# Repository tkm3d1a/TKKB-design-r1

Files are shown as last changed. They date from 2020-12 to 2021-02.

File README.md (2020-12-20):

# TKKB-design-r1
 TKm3d1a Keyboard design project, revision 1

MY first attempt at using Github for rev control and publishing of any/all files in KB design.

The Goal is a 60% ish keyboard design, no multiple layout support.  Exposed diodes, with a swapable MCU.

Possibly also add numpad support as I personally use the numpad often.  

Designed to use PCB mount MX style switches.

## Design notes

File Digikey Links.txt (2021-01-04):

MCU - ATMega32A
https://www.digikey.com/en/products/detail/microchip-technology/ATMEGA32A-PU/1914592

Crystal - HC49 Pkg - LFXTAL003231BULK
https://www.digikey.com/en/products/detail/iqd-frequency-products/LFXTAL003231BULK/8633676

22uF Cap - Radial, Can D5x2 Pkg - ECE-A1AN220U
https://www.digikey.com/en/products/detail/panasonic-electronic-components/ECE-A1AN220U/227593

4u7F Cap - Radial, Can D5x2 Pkg - UKL1E4R7KDDANA
https://www.digikey.com/en/products/detail/nichicon/UKL1E4R7KDDANA/2598437

0u1F Cap - Disc, 5.1Lx3.2W with 5.1 Pitch - SR215C104JARTR1
https://www.digikey.com/en/products/detail/avx-corporation/SR215C104JARTR1/9948450

5k1 RES - Axial, Horiz, 3.6x1.6 - MBA02040C5101FCT00
https://www.digikey.com/en/products/detail/vishay-beyschlag-draloric-bc-components/MBA02040C5101FCT00/6138797

10k RES - Axial, Horiz, 3.6x1.6 - MRS16000C1002FRP00
https://www.digikey.com/en/products/detail/vishay-beyschlag-draloric-bc-components/MRS16000C1002FRP00/5063735

75R RES - Axial, Horiz, 3.6x1.6 - MBA02040C7509FC100
https://www.digikey.com/en/products/detail/vishay-beyschlag-draloric-bc-components/MBA02040C7509FC100/7350982

3.6v Z-Diode - Axial, DO-35 PKG - BZX79-C3V6,133
https://www.digikey.com/en/products/detail/nexperia-usa-inc/BZX79-C3V6133/2762641

Gen Purp 75V/300mA Diode - Axial, DO-35 PKG - 1N4148TR
https://www.digikey.com/en/products/detail/vishay-semiconductor-diodes-division/1N4148TR/3104054

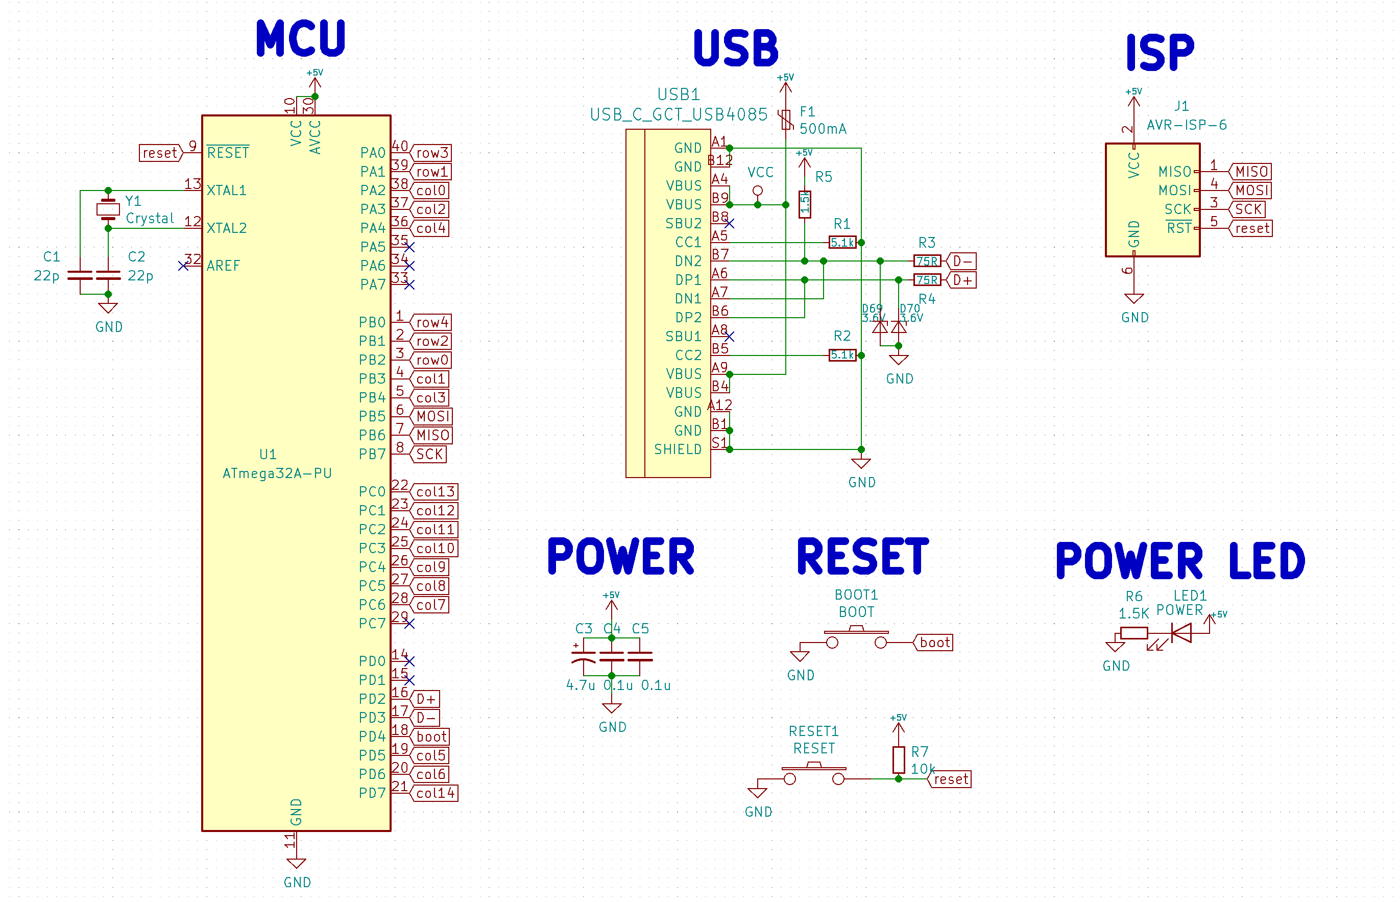
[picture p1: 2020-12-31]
Pictures/Discipline_schematic_snip.png

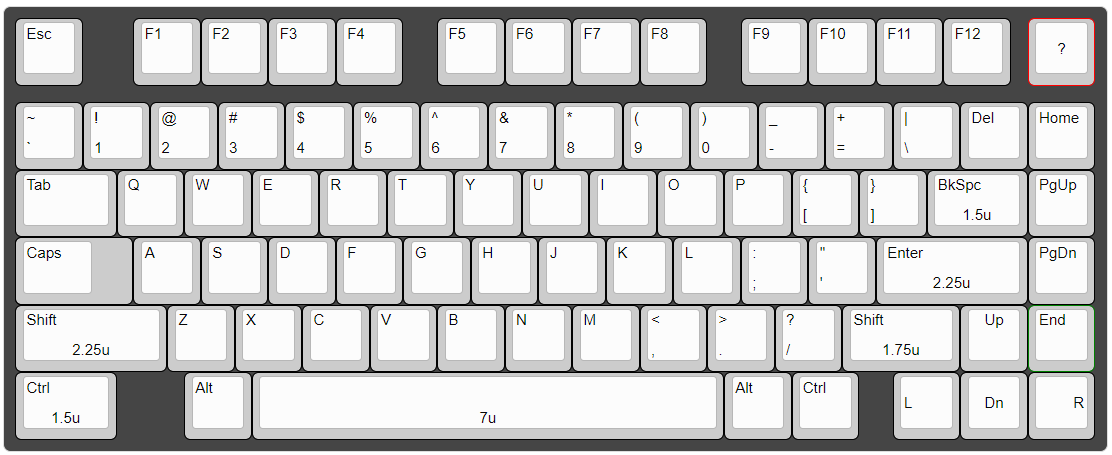
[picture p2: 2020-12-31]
Pictures/KLE Layout GMKStealth_BASE_Custom.png

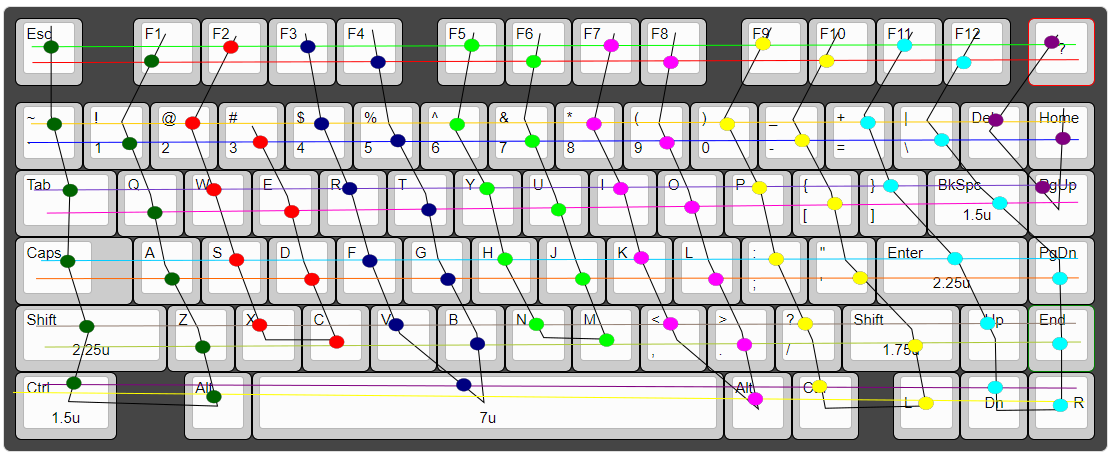
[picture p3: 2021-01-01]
Pictures/RowCol_GMKStealth.png

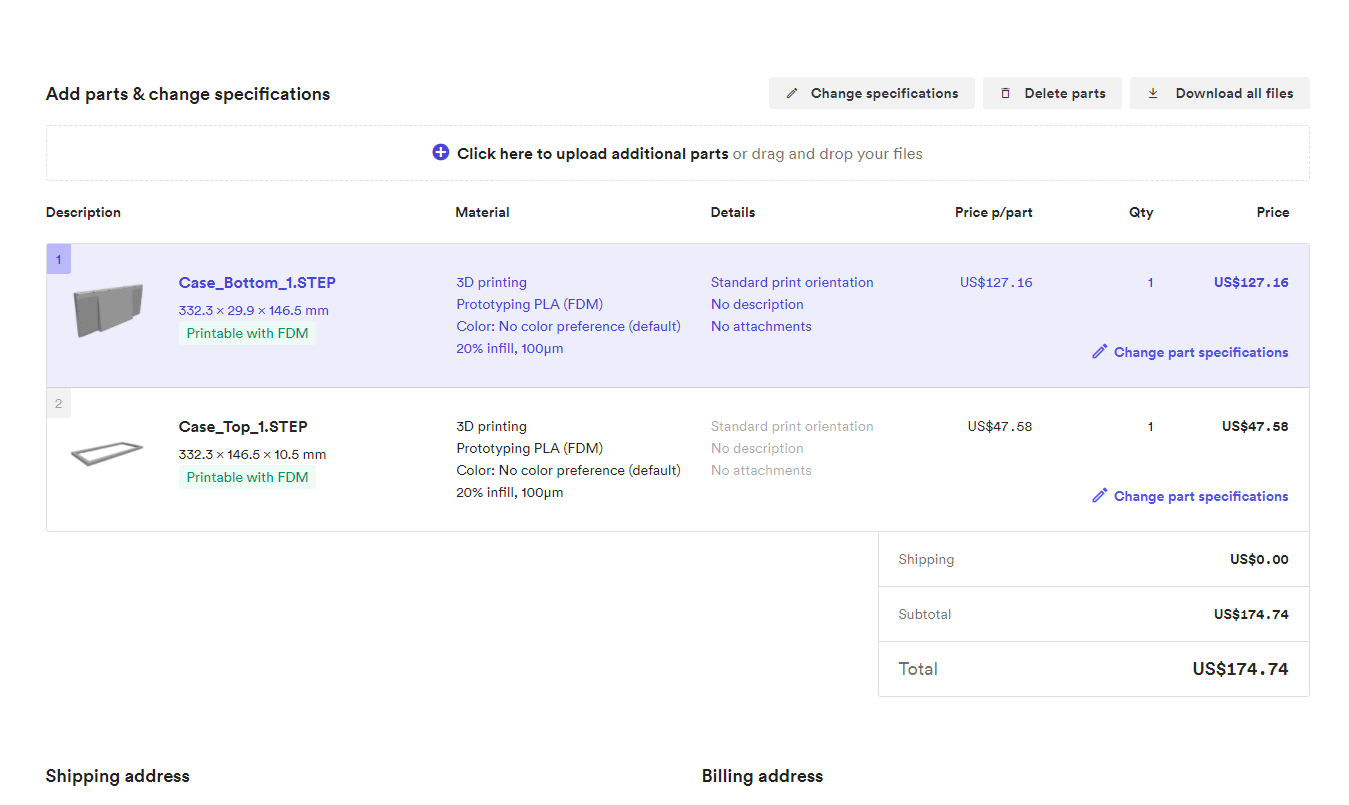
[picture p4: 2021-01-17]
CAD Files/For MFG - R1/3dhub_FDM_Bot and Top Quote.png

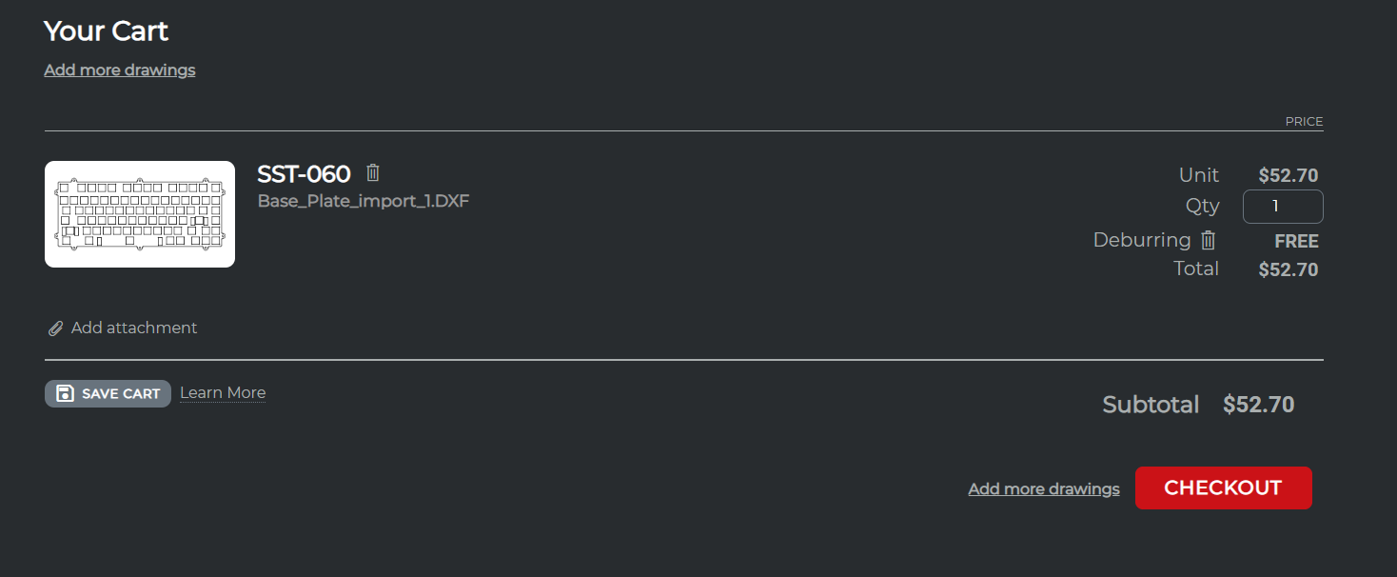
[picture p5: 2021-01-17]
CAD Files/For MFG - R1/ScS_Plate_Quote.png

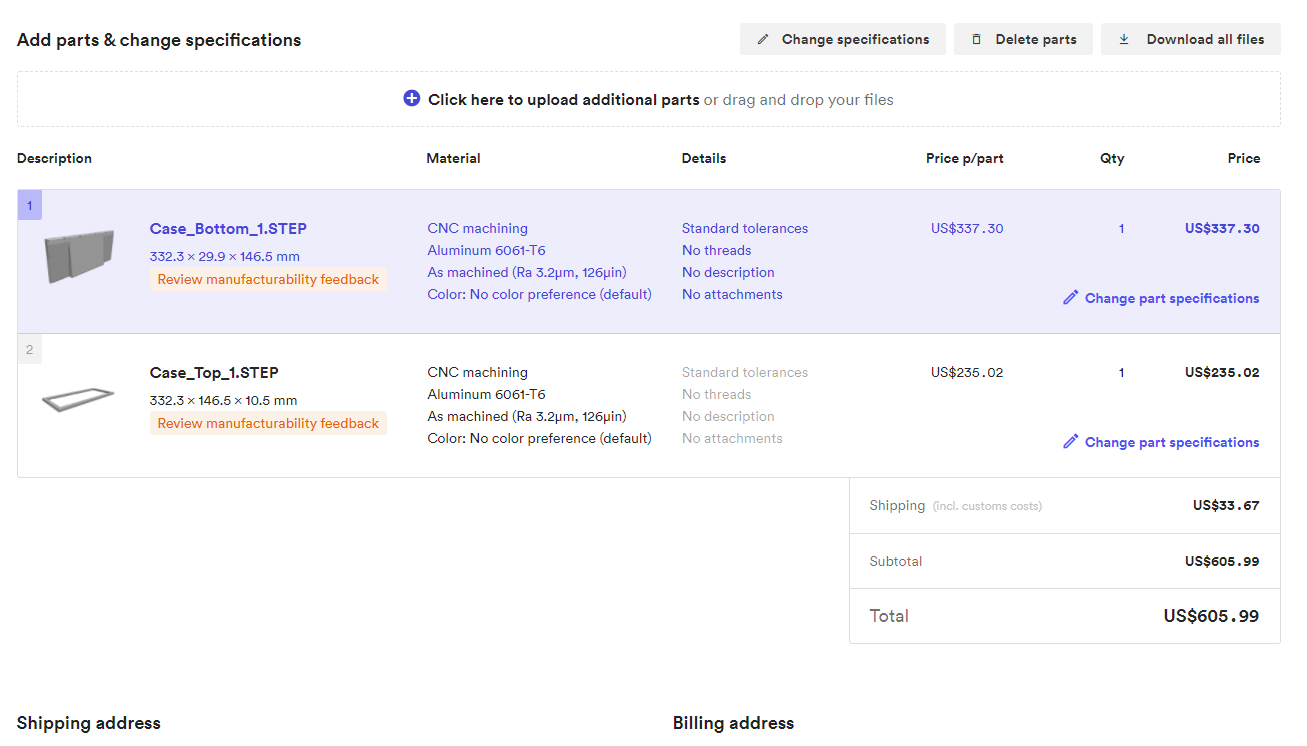
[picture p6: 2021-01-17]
CAD Files/For MFG - R1/3dhub_cnc_Bot and Top Quote.png

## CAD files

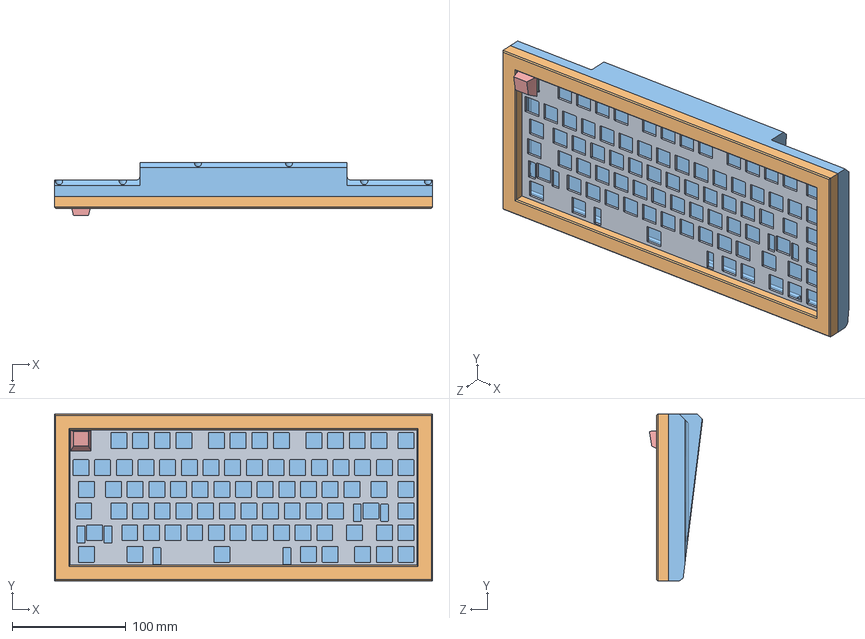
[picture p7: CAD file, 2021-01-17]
CAD Files/TKKB - Assy design - r1.SLDASM
332.3 x 146.5 x 46.9 mm
Base_Plate_import_1
Case_Top_1
Case_Bottom_1
SW_Cherry_MX_PCB
R1_cherry_1U_keycap
9262K511_MULTIPURPOSE O-RING x 20
92290A058_TYPE 316 SS SOCKET HEAD CAP SCREW x 10
92290A113_TYPE 316 SS SOCKET HEAD CAP SCREW x 16

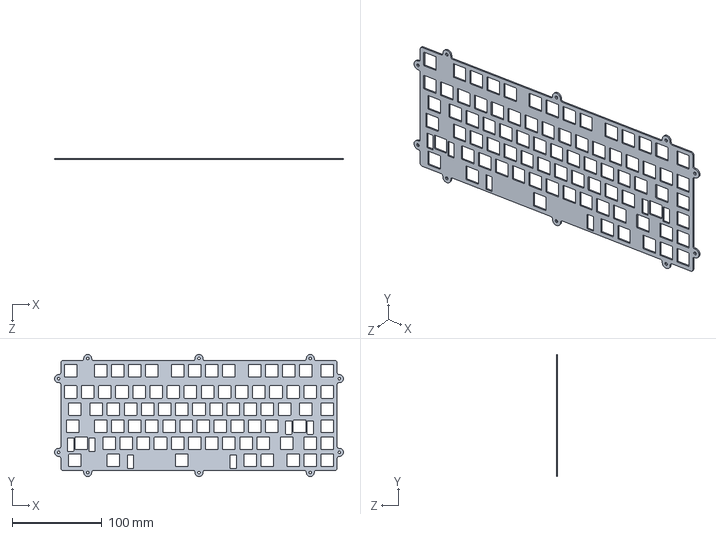
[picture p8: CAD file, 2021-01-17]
CAD Files/Base_Plate_import_1.SLDPRT
321.8 x 136.0 x 1.50 mm

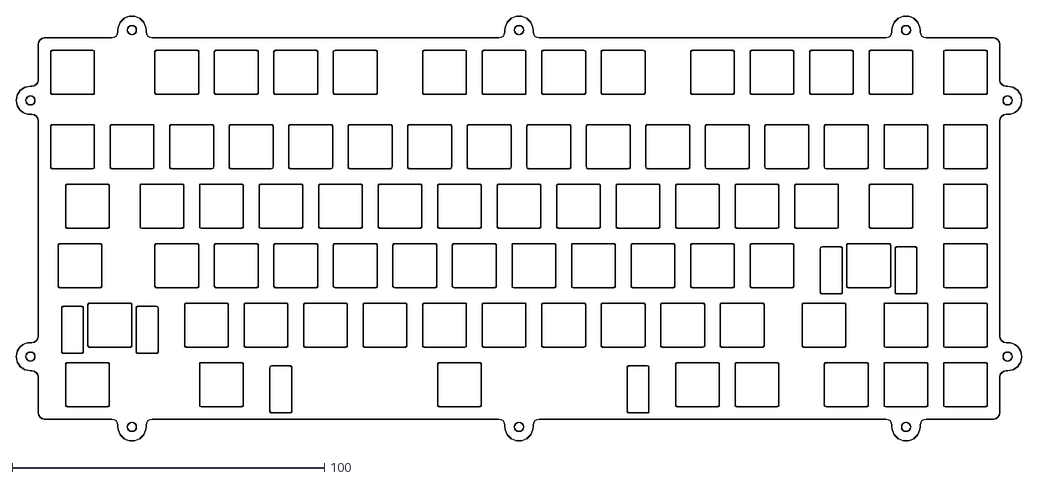
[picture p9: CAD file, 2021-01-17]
CAD Files/For MFG - R1/Base_Plate_import_1.DXF
321.8 x 136.0

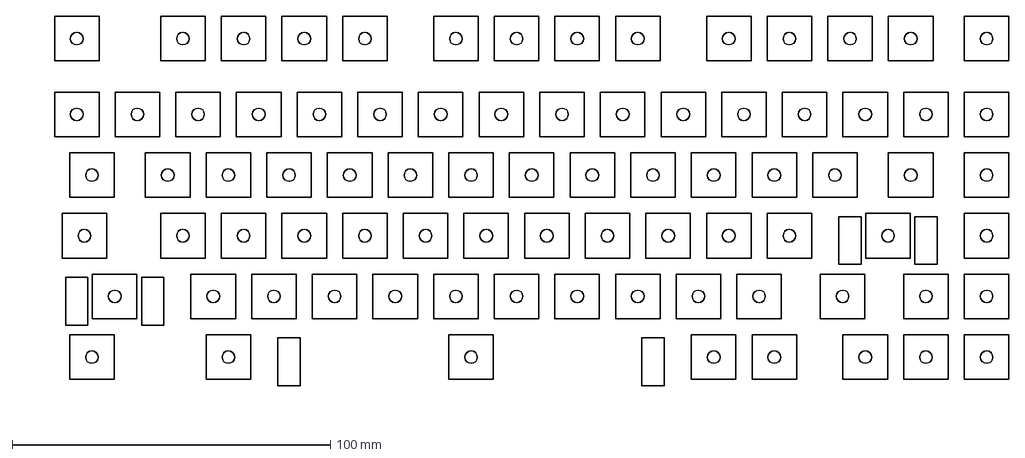
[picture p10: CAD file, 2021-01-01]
Plate DXF Options/KLE_GMKStealth65Per_LibreCad.dxf
311.8 x 126.1 mm

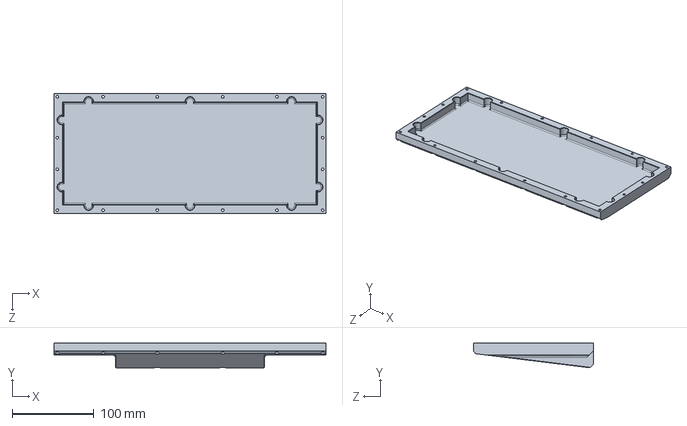
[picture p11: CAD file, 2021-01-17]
CAD Files/Case_Bottom_1.SLDPRT
332.3 x 29.9 x 146.5 mm

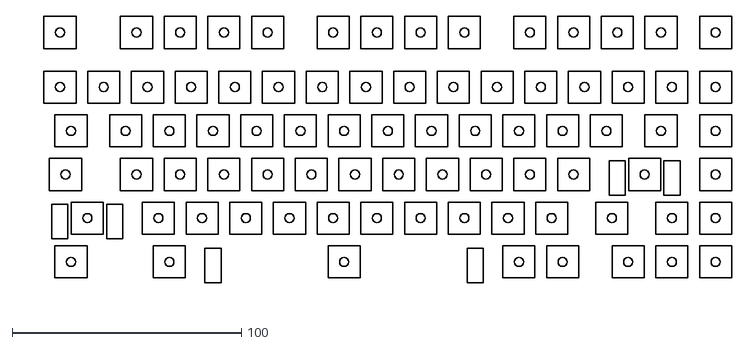
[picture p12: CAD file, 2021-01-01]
Plate DXF Options/KLE_GMKStealth65Per_LibreCad_R12.dxf
311.8 x 126.1

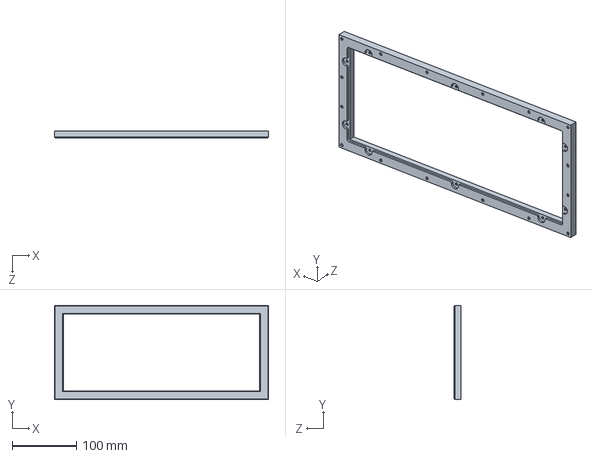
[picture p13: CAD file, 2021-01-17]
CAD Files/For MFG - R1/Case_Top_1.STEP
332.3 x 146.5 x 10.5 mm

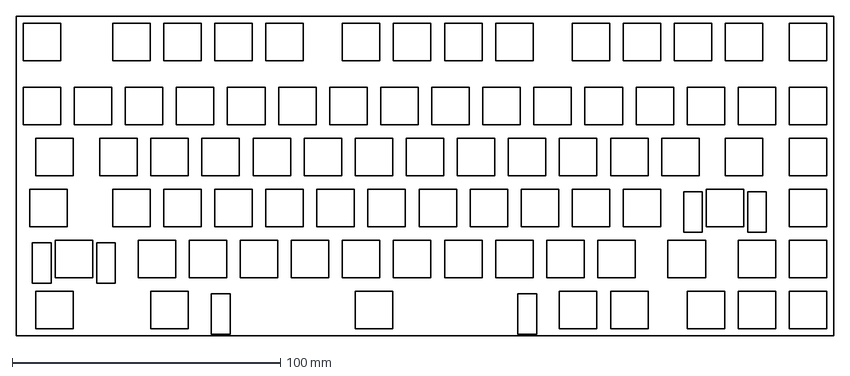
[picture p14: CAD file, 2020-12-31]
Plate DXF Options/KLE_GMKStealth65Per.dxf
304.8 x 119.1 mm

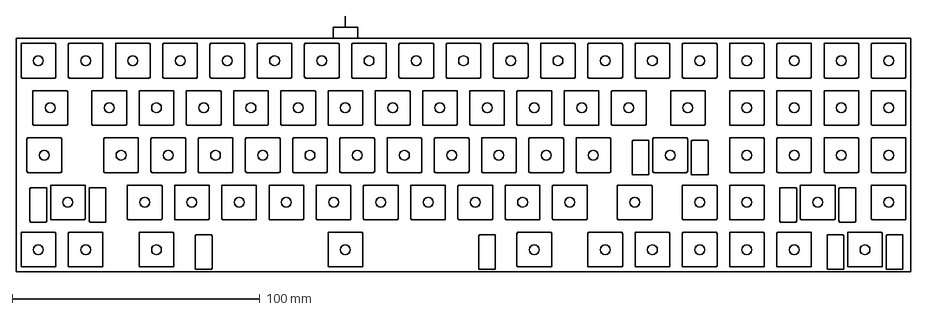
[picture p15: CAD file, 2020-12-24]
Plate DXF Options/TKKB_60ish_LibreCad.dxf
360.9 x 103.2 mm

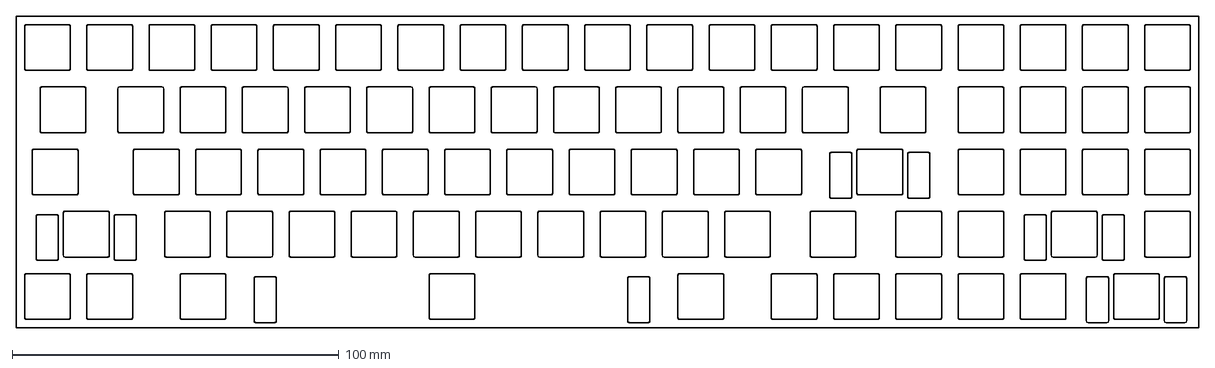
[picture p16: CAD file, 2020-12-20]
Plate DXF Options/TKKB_60ish_RAW.dxf
361.9 x 95.2 mm

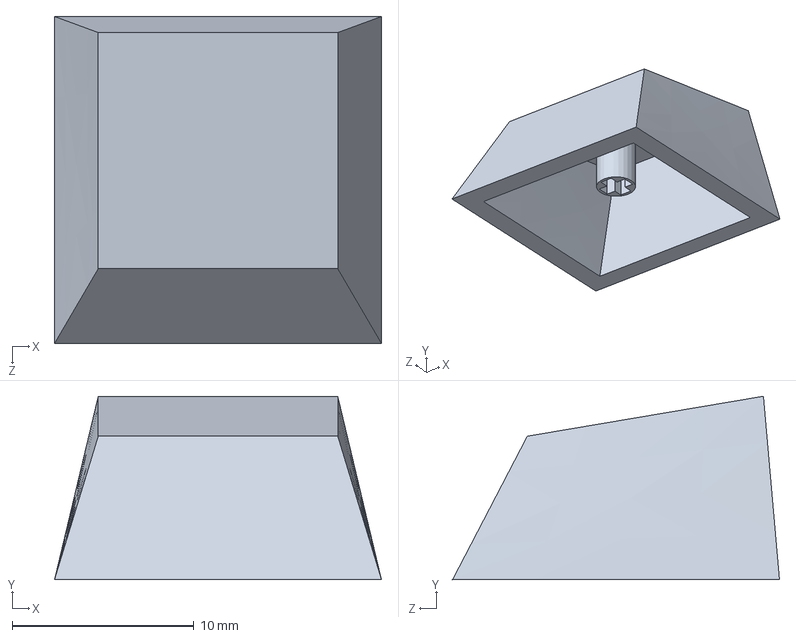
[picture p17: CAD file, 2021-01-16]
CAD Files/R1_cherry_1U_keycap.SLDPRT
18.0 x 10.1 x 18.0 mm

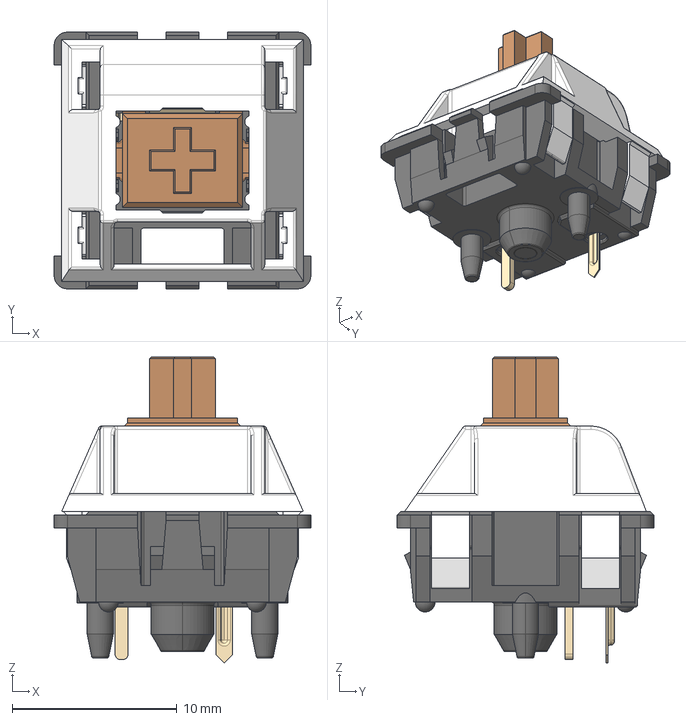
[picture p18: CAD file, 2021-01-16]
CAD Files/SW_Cherry_MX_PCB.step
15.6 x 15.6 x 18.6 mm

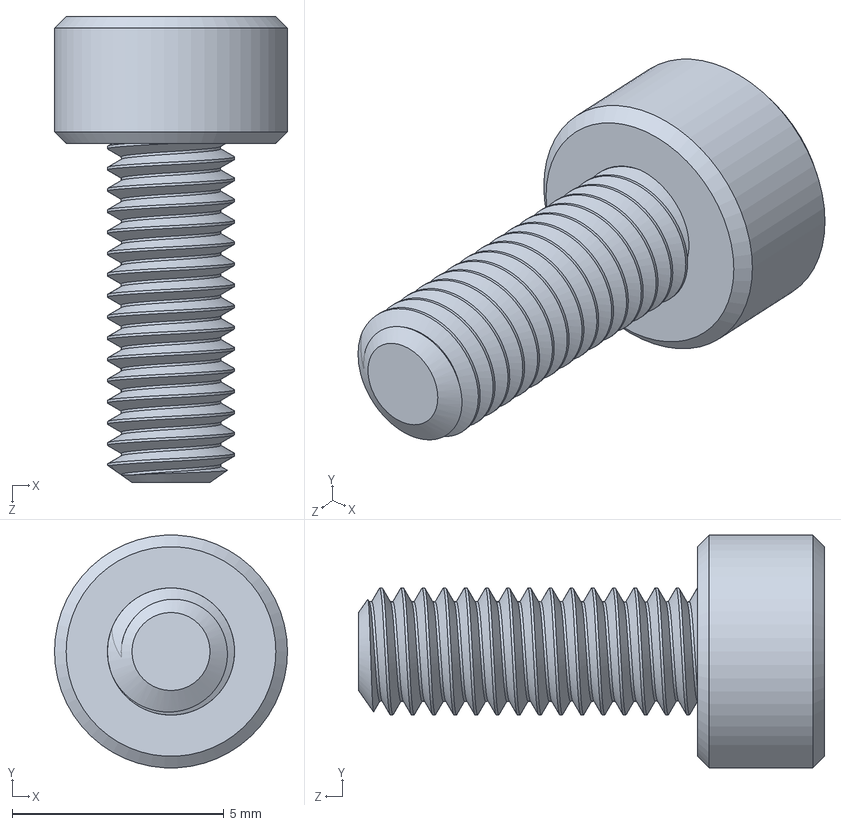
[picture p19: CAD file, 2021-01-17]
CAD Files/92290A113_TYPE 316 SS SOCKET HEAD CAP SCREW.SLDPRT
5.50 x 5.49 x 11.0 mm

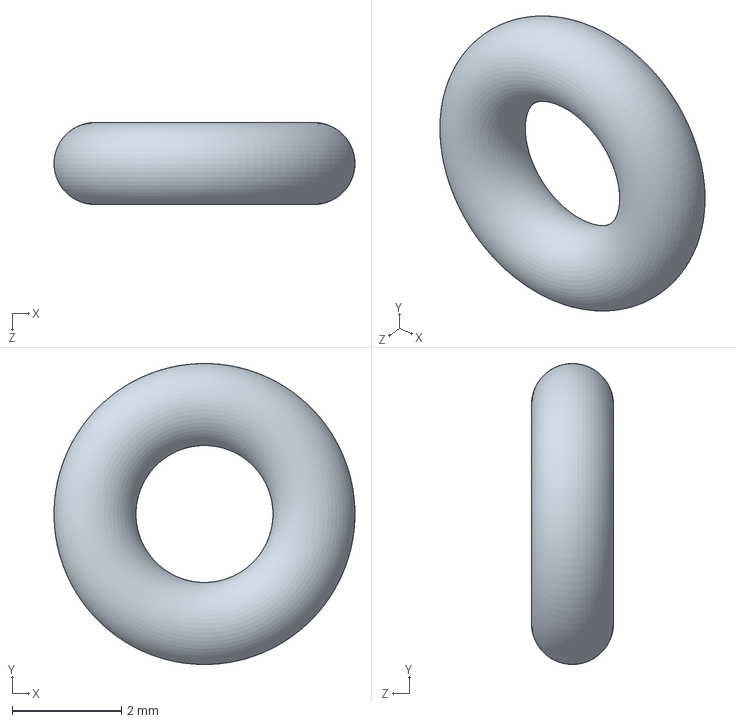
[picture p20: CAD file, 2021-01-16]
CAD Files/1174N211_ULTRA-COMPRESSIBLE O-RING.SLDPRT
5.50 x 5.50 x 1.50 mm

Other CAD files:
CAD Files/For MFG - R1/Case_Bottom_1.STEP
CAD Files/Case_Top_1.SLDPRT
CAD Files/92290A058_TYPE 316 SS SOCKET HEAD CAP SCREW.SLDPRT
CAD Files/9262K511_MULTIPURPOSE O-RING.SLDPRT
CAD Files/SW_Cherry_MX_PCB.SLDPRT

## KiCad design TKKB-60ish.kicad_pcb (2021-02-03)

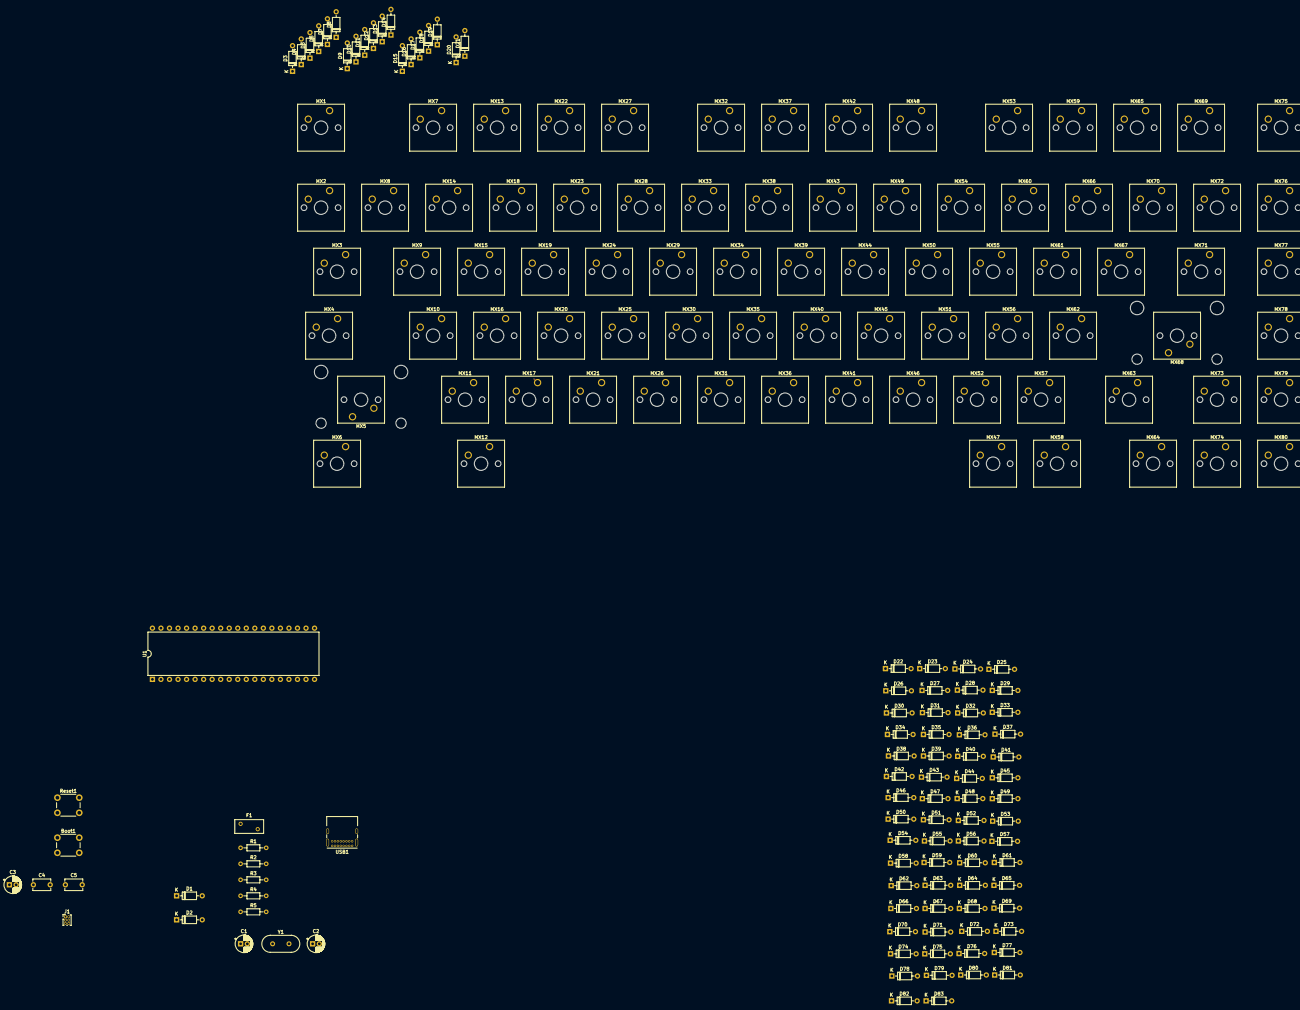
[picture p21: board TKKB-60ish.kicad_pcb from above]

Board: 2 copper layers, 180 parts (0 on the bottom side), 116 nets.

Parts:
Boot1: Boot; SW_PUSH_6mm
C1, C2: 22p; CP_Radial_D5.0mm_P2.00mm
C3: 4u7; CP_Radial_D5.0mm_P2.00mm
C4, C5: 0u1; C_Disc_D5.1mm_W3.2mm_P5.00mm
D1, D2: 3.6V; D_DO-35_SOD27_P7.62mm_Horizontal
D3, D4, D5, D6, D7, D8, D9, D10, D11, D12, D13, D14, D15, D16, D17, D18, D19, D20, D21, D22, D23, D24, D25, D26, D27, D28, D29, D30, D31, D32, D33, D34, D35, D36, D37, D38, D39, D40, D41, D42, D43, D44, D45, D46, D47, D48, D49, D50, D51, D52, D53, D54, D55, D56, D57, D58, D59, D60, D61, D62, D63, D64, D65, D66, D67, D68, D69, D70, D71, D72, D73, D74, D75, D76, D77, D78, D79, D80, D81, D82, D83: 1N4148TR; D_DO-35_SOD27_P7.62mm_Horizontal
F1: 500mA; Fuse_BelFuse_0ZRE0005FF_L8.3mm_W3.8mm
J1: AVR-ISP-6; PinHeader_2x03_P1.00mm_Vertical
MX1: Esc; SW_Cherry_MX_1.00u_PCB
MX2: Tilde; SW_Cherry_MX_1.00u_PCB
MX3: Tab; SW_Cherry_MX_1.50u_PCB
MX4: Step Caps; SW_Cherry_MX_1.00u_PCB
MX5: Shift; SW_Cherry_MX_2.25u_PCB
MX6: Ctrl; SW_Cherry_MX_1.50u_PCB
MX7: F1; SW_Cherry_MX_1.00u_PCB
MX8: 1; SW_Cherry_MX_1.00u_PCB
MX9: Q; SW_Cherry_MX_1.00u_PCB
MX10: A; SW_Cherry_MX_1.00u_PCB
MX11: Z; SW_Cherry_MX_1.00u_PCB
MX12: Alt; SW_Cherry_MX_1.00u_PCB
MX13: F2; SW_Cherry_MX_1.00u_PCB
MX14: 2; SW_Cherry_MX_1.00u_PCB
MX15: W; SW_Cherry_MX_1.00u_PCB
MX16: S; SW_Cherry_MX_1.00u_PCB
MX17: X; SW_Cherry_MX_1.00u_PCB
MX18: 3; SW_Cherry_MX_1.00u_PCB
MX19: E; SW_Cherry_MX_1.00u_PCB
MX20: D; SW_Cherry_MX_1.00u_PCB
MX21: C; SW_Cherry_MX_1.00u_PCB
MX22: F3; SW_Cherry_MX_1.00u_PCB
MX23: 4; SW_Cherry_MX_1.00u_PCB
MX24: R; SW_Cherry_MX_1.00u_PCB
MX25: F; SW_Cherry_MX_1.00u_PCB
MX26: V; SW_Cherry_MX_1.00u_PCB
MX27: F4; SW_Cherry_MX_1.00u_PCB
MX28: 5; SW_Cherry_MX_1.00u_PCB
MX29: T; SW_Cherry_MX_1.00u_PCB
MX30: G; SW_Cherry_MX_1.00u_PCB
MX31: B; SW_Cherry_MX_1.00u_PCB
MX32: F5; SW_Cherry_MX_1.00u_PCB
MX33: 6; SW_Cherry_MX_1.00u_PCB
MX34: Y; SW_Cherry_MX_1.00u_PCB
MX35: H; SW_Cherry_MX_1.00u_PCB
MX36: N; SW_Cherry_MX_1.00u_PCB
MX37: F6; SW_Cherry_MX_1.00u_PCB
MX38: 7; SW_Cherry_MX_1.00u_PCB
MX39: U; SW_Cherry_MX_1.00u_PCB
MX40: J; SW_Cherry_MX_1.00u_PCB
MX41: M; SW_Cherry_MX_1.00u_PCB
MX42: F7; SW_Cherry_MX_1.00u_PCB
MX43: 8; SW_Cherry_MX_1.00u_PCB
MX44: I; SW_Cherry_MX_1.00u_PCB
MX45: K; SW_Cherry_MX_1.00u_PCB
MX46: <; SW_Cherry_MX_1.00u_PCB
MX47: R Alt; SW_Cherry_MX_1.00u_PCB
MX48: F8; SW_Cherry_MX_1.00u_PCB
MX49: 9; SW_Cherry_MX_1.00u_PCB
MX50: O; SW_Cherry_MX_1.00u_PCB
MX51: L; SW_Cherry_MX_1.00u_PCB
MX52: >; SW_Cherry_MX_1.00u_PCB
MX53: F9; SW_Cherry_MX_1.00u_PCB
MX54: 0; SW_Cherry_MX_1.00u_PCB
MX55: P; SW_Cherry_MX_1.00u_PCB
MX56: ;; SW_Cherry_MX_1.00u_PCB
MX57: /; SW_Cherry_MX_1.00u_PCB
MX58: R Ctrl; SW_Cherry_MX_1.00u_PCB
MX59: F10; SW_Cherry_MX_1.00u_PCB
MX60: -; SW_Cherry_MX_1.00u_PCB
MX61: [; SW_Cherry_MX_1.00u_PCB
MX62: '; SW_Cherry_MX_1.00u_PCB
MX63: RShift; SW_Cherry_MX_1.75u_PCB
MX64: Left Arrow; SW_Cherry_MX_1.00u_PCB
MX65: F11; SW_Cherry_MX_1.00u_PCB
MX66: =; SW_Cherry_MX_1.00u_PCB
MX67: ]; SW_Cherry_MX_1.00u_PCB
MX68: Enter; SW_Cherry_MX_2.25u_PCB
MX69: F12; SW_Cherry_MX_1.00u_PCB
MX70: \; SW_Cherry_MX_1.00u_PCB
MX71: bACKSPACE; SW_Cherry_MX_1.50u_PCB
MX72: Del; SW_Cherry_MX_1.00u_PCB
MX73: Up Arrow; SW_Cherry_MX_1.00u_PCB
MX74: Down Arrow; SW_Cherry_MX_1.00u_PCB
MX75: ?; SW_Cherry_MX_1.00u_PCB
MX76: Home; SW_Cherry_MX_1.00u_PCB
MX77: PgUp; SW_Cherry_MX_1.00u_PCB
MX78: PgDn; SW_Cherry_MX_1.00u_PCB
MX79: End; SW_Cherry_MX_1.00u_PCB
MX80: Right Arrow; SW_Cherry_MX_1.00u_PCB
R1, R2: 5k1; R_Axial_DIN0204_L3.6mm_D1.6mm_P7.62mm_Horizontal
R3: 10k; R_Axial_DIN0204_L3.6mm_D1.6mm_P7.62mm_Horizontal
R4, R5: 75R; R_Axial_DIN0204_L3.6mm_D1.6mm_P7.62mm_Horizontal
Reset1: Reset; SW_PUSH_6mm
U1: ATmega32A-PU; DIP-40_W15.24mm
USB1: Type-C_USB_C_GCT_USB4085; USB_C_Receptacle_GCT_USB4085
Y1: 16MHz; Crystal_HC49-U_Vertical

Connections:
+5V: C3.1, C4.1, C5.1, F1.1, J1.2, R3.1, U1.10, U1.30
/Keyboard Matrix/Col_0: MX1.1, MX2.1, MX3.1, MX4.1, MX5.1, MX6.1, MX7.1, MX8.1, MX9.1, MX10.1, MX11.1, MX12.1
/Keyboard Matrix/Col_1: MX13.1, MX14.1, MX15.1, MX16.1, MX17.1, MX18.1, MX19.1, MX20.1, MX21.1
/Keyboard Matrix/Col_2: MX22.1, MX23.1, MX24.1, MX25.1, MX26.1, MX27.1, MX28.1, MX29.1, MX30.1, MX31.1
/Keyboard Matrix/Col_3: MX32.1, MX33.1, MX34.1, MX35.1, MX36.1, MX37.1, MX38.1, MX39.1, MX40.1, MX41.1
/Keyboard Matrix/Col_4: MX42.1, MX43.1, MX44.1, MX45.1, MX46.1, MX47.1, MX48.1, MX49.1, MX50.1, MX51.1, MX52.1
/Keyboard Matrix/Col_5: MX53.1, MX54.1, MX55.1, MX56.1, MX57.1, MX58.1, MX59.1, MX60.1, MX61.1, MX62.1, MX63.1, MX64.1
/Keyboard Matrix/Col_6: MX65.1, MX66.1, MX67.1, MX68.1, MX69.1, MX70.1, MX71.1, MX73.1, MX74.1, MX78.1, MX79.1, MX80.1
/Keyboard Matrix/Col_7: MX72.1, MX75.1, MX76.1, MX77.1
/Keyboard Matrix/Row_0: D3.1, D15.1, D24.1, D35.1, D45.1, D56.1, D68.1, D78.1
/Keyboard Matrix/Row_1: D9.1, D29.1, D40.1, D51.1, D62.1, D72.1
/Keyboard Matrix/Row_2: D4.1, D16.1, D25.1, D36.1, D46.1, D57.1, D69.1, D75.1
/Keyboard Matrix/Row_3: D10.1, D20.1, D30.1, D41.1, D52.1, D63.1, D73.1, D79.1
/Keyboard Matrix/Row_4: D5.1, D17.1, D26.1, D37.1, D47.1, D58.1, D70.1, D80.1
/Keyboard Matrix/Row_5: D11.1, D21.1, D31.1, D42.1, D53.1, D64.1, D74.1
/Keyboard Matrix/Row_6: D6.1, D18.1, D27.1, D38.1, D48.1, D59.1, D71.1
/Keyboard Matrix/Row_7: D12.1, D22.1, D32.1, D43.1, D54.1, D65.1, D81.1
/Keyboard Matrix/Row_8: D7.1, D19.1, D28.1, D39.1, D49.1, D60.1, D76.1
/Keyboard Matrix/Row_9: D13.1, D23.1, D33.1, D44.1, D55.1, D66.1, D82.1
/Keyboard Matrix/Row_10: D8.1, D50.1, D61.1, D77.1
/Keyboard Matrix/Row_11: D14.1, D34.1, D67.1, D83.1
Boot: Boot1.2, U1.18
D+: R5.1, U1.16
D-: R4.1, U1.17
GND: Boot1.1, C1.2, C2.1, C3.2, C4.2, C5.2, D1.2, D2.2, J1.6, R1.2, R2.2, Reset1.1, U1.11, U1.31, USB1.A1, USB1.A12, USB1.B1, USB1.B12, USB1.S1
MISO: J1.1, U1.7
MOSI: J1.4, U1.6
unnamed: C1.1, U1.13, Y1.1
unnamed: C2.2, U1.12, Y1.2
unnamed: D1.1, R5.2, USB1.A6, USB1.B6
unnamed: D2.1, R4.2, USB1.A7, USB1.B7
unnamed: D3.2, MX1.2
unnamed: D4.2, MX2.2
unnamed: D5.2, MX3.2
unnamed: D6.2, MX4.2
unnamed: D7.2, MX5.2
unnamed: D8.2, MX6.2
unnamed: D9.2, MX7.2
unnamed: D10.2, MX8.2
unnamed: D11.2, MX9.2
unnamed: D12.2, MX10.2
unnamed: D13.2, MX11.2
unnamed: D14.2, MX12.2
unnamed: D15.2, MX13.2
unnamed: D16.2, MX14.2
unnamed: D17.2, MX15.2
unnamed: D18.2, MX16.2
unnamed: D19.2, MX17.2
unnamed: D20.2, MX18.2
unnamed: D21.2, MX19.2
unnamed: D22.2, MX20.2
unnamed: D23.2, MX21.2
unnamed: D24.2, MX22.2
unnamed: D25.2, MX23.2
unnamed: D26.2, MX24.2
unnamed: D27.2, MX25.2
unnamed: D28.2, MX26.2
unnamed: D29.2, MX27.2
unnamed: D30.2, MX28.2
unnamed: D31.2, MX29.2
unnamed: D32.2, MX30.2
unnamed: D33.2, MX31.2
unnamed: D35.2, MX32.2
unnamed: D36.2, MX33.2
unnamed: D37.2, MX34.2
unnamed: D38.2, MX35.2
unnamed: D39.2, MX36.2
unnamed: D40.2, MX37.2
unnamed: D41.2, MX38.2
unnamed: D42.2, MX39.2
unnamed: D43.2, MX40.2
unnamed: D44.2, MX41.2
unnamed: D45.2, MX42.2
unnamed: D46.2, MX43.2
unnamed: D47.2, MX44.2
unnamed: D48.2, MX45.2
unnamed: D49.2, MX46.2
unnamed: D50.2, MX47.2
unnamed: D51.2, MX48.2
unnamed: D52.2, MX49.2
unnamed: D53.2, MX50.2
unnamed: D54.2, MX51.2
unnamed: D55.2, MX52.2
unnamed: D56.2, MX53.2
unnamed: D57.2, MX54.2
unnamed: D58.2, MX55.2
unnamed: D59.2, MX56.2
unnamed: D60.2, MX57.2
unnamed: D61.2, MX58.2
unnamed: D62.2, MX59.2
unnamed: D63.2, MX60.2
unnamed: D64.2, MX61.2
unnamed: D65.2, MX62.2
unnamed: D66.2, MX63.2
unnamed: D67.2, MX64.2
unnamed: D68.2, MX65.2
unnamed: D69.2, MX66.2
unnamed: D70.2, MX67.2
unnamed: D71.2, MX68.2
unnamed: D72.2, MX69.2
unnamed: D73.2, MX70.2
unnamed: D74.2, MX71.2
unnamed: D75.2, MX72.2
unnamed: D76.2, MX73.2
unnamed: D77.2, MX74.2
unnamed: D78.2, MX75.2
unnamed: D79.2, MX76.2
unnamed: D80.2, MX77.2
unnamed: D81.2, MX78.2
unnamed: D82.2, MX79.2
unnamed: D83.2, MX80.2
unnamed: R1.1, USB1.A5
unnamed: R2.1, USB1.B5
Reset: J1.5, R3.2, Reset1.2, U1.9
SCK: J1.3, U1.8
USB_Vbus: F1.2, USB1.A4, USB1.A9, USB1.B4, USB1.B9

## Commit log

2020-12-20 Added Plate Raw DXF
    [TKKB-60ish.kicad_pcb, TKKB-60ish.sch, TKKB_60ish_RAW.dxf]
2020-12-21 EOD 12-20-20
    [TKKB-60ish.sch]
2020-12-24 LibreCad DXF Edits/Grid Layout
    [TKKB_60ish_LibreCad.dxf]
2020-12-24 Schematic Updated - still in work
    [TKKB-60ish.sch]
2020-12-31 Add Type-c pretty
    [TKKB-60ish.sch]
2020-12-31 Reorg Folder Structure
    [KLE_GMKStealth65Per.dxf, TKKB_60ish_LibreCad.dxf, TKKB_60ish_RAW.dxf]
2021-01-01 Added USB/Boot/ISP/Init MCU to schematic
    [TKKB-60ish.sch]
2021-01-01 PCB Layout edits
    [KLE_GMKStealth65Per_LibreCad.dxf, KLE_GMKStealth65Per_LibreCad_R12.dxf, TKKB-60ish.sch]
2021-01-02 Updated Schematic
    [Keyboard Matrix.sch, TKKB-60ish.sch]
2021-01-02 Begin Cad Files
    [Base_Plate_import_1.SLDPRT]
2021-01-04 update to kicad schematic and pcb
    [Keyboard Matrix.sch, TKKB-60ish.kicad_pcb, TKKB-60ish.sch]
2021-01-12 Added some CAD
    [Base_Plate_import_1.SLDPRT, TKKB - Assy design - r1.SLDASM]
2021-01-16 Updated CAD/Added some KiCad Footprints
    [Base_Plate_import_1.SLDPRT, Case_Top_1.SLDPRT, R1_cherry_1U_keycap.SLDPRT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]
2021-01-16 Cad updates
    [1174N211_ULTRA-COMPRESSIBLE O-RING.SLDPRT, 92290A058_TYPE 316 SS SOCKET HEAD CAP SCREW.SLDPRT, 9262K511_MULTIPURPOSE O-RING.SLDPRT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]
2021-01-16 Mopre cad updates(82keys)
    [92290A058_TYPE 316 SS SOCKET HEAD CAP SCREW.SLDPRT, Base_Plate_import_1.SLDPRT, Case_Top_1.SLDPRT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]
2021-01-17 Case r1 Complete
    [92290A058_TYPE 316 SS SOCKET HEAD CAP SCREW.SLDPRT, 92290A113_TYPE 316 SS SOCKET HEAD CAP SCREW.SLDPRT, Case_Bottom_1.SLDPRT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]
2021-01-17 Quotes added for R1 prototype
    [Base_Plate_import_1.DXF, Base_Plate_import_1.SLDPRT, Case_Bottom_1.STEP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]
2021-02-03 Board layout work
    [Keyboard Matrix.sch, TKKB-60ish.kicad_pcb, TKKB-60ish.sch]
